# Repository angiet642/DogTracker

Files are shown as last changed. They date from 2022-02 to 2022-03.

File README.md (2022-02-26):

# DogTracker
__Authors: Kylee and Angie__

### Purpose 

A common issue pet-owners face is discovering that their pet has escaped the house. To prevent this situation, our team is interested in designing a low-power dog tracker using LoRa. Unlike other pet-tracking collars, our system will implement a training technique by emitting a 25KHz sound wave if the pet is found outside of a user-defined geo fence. For example, if the user would like to train their dog to avoid a specific area of the backyard, our device will detect whether the dog is in this region and emit the high frequency sound if so.

### System diagram   
The proposed design of the pet-tracker system is illustrated in the block diagram below.
<p>
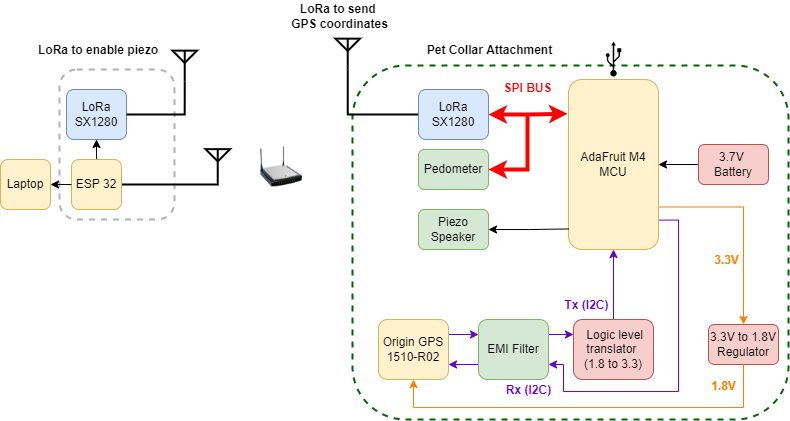
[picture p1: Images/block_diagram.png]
  
  <p> Figure 1: System Level Block Diagram
</p>

### Proposed schedule
| Week  | Date | Tasks 
| --- | --- | --- |
| Week 7 | Feb 13-Feb 19  | - [x] Order parts <br />- [ ] Review PCB and Schematic with Steve and Joanna |
| Week 8 | Feb 20-Feb 26  | - [x] Submit PCB for fabriciation | 
| Week 9 | Feb 27-March 5  | - [ ] Bring up and test boards | 
| Week 10 | March 6-March 12  | - [ ] Demo | 

### Verification
To verify our system, we will first verify the functionality of each module before methodically combining things into our final system. The steps are outlined below.

#### Before final PCB comes back: 
- [x] Upload basic Blink code to M4 Feather Board
- [x] Write basic transmit/recieve code for SX1280 using this [reference](https://github.com/maholli/CircuitPython_SX1280) (In progress)
- [ ] Hook up SX1280 to SPI port of any available micro and run transmit code while probing antenna line with Spectrum Analyzer
- [ ] Connect additional SX1280 board and have both transmit and recieve data \
#### After final PCB comes back:
- [ ] Again, verify transmit and recieve of SX1280 module on our PCB
- [ ] Connect SX1280 to ESP32 (the "base station") and try sending and recieving from our PCB
- [ ] Connect ESP32 to wifi and verify that there isn't any interference between Lora and WIFI
- [ ] Independently turn on GPS and test reading cordinates
- [ ] Turn on both SX1280 and GPS and run code to intermittently send GPS coordinates to "base station" 
- [ ] Configure pedometer to read step count on the microcontroller
- [ ] Read pedometer at the same time as reading GPS and sending Lora
- [ ] Confgure Ultrasonic piezo buzzer and try running at 25kHz, certain apps will verify sound since it's beyond the human range
- [ ] Upload code for runnng piezzo buzzer from the "base station" when dog is out of range
- [ ] Run all four modules at the same time 
- [ ] Have "base station"  upload information to a website hosted on the the Things network

### Demo Plan
Our demo will be putting the collar on a fellow classmate and having them run around the engineering quad to show the real time updates in GPS coordinates on the base station, which will be set up in the lab. Finally, we will show that when our classmate goes out of the user-defined range, the piezzo buzzer will turn on which can be verified with [this app](https://play.google.com/store/apps/details?id=com.microcadsystems.serge.ultrasounddetector&hl=en_US&gl=US)

### In our write up, we will discuss the following
- importance and novelty of the idea 
- description of chosen features 
- high level system discussion
- schematic walkthrough 
- examination of different protocols SPI/I2C/UART 
- Review of RF components eg LoRa, WiFi 
- analysis of challenges or drawbacks
- improvements going forward 
- concluding remarks on our project 

### Challenges
The most difficult steps is getting the PCB right the first time around. We have been meticulously researching parts and going through datasheets to make sure we understand everything that we need for our final PCB. We also plan to have Joanna, Greig, and Steve verify the schematic before we submit it to JLCPCB. 

We have already gotten our parts list checked off and ordered. After submitting our final PCB, we will begin working on the software side of our project. There is a sufficient amount of code to write but none will be outside of our domain given that there's a lot of GPS/LORA/SPI/I2C libraries in Circuit python. 

### Project Links:
Bill of Materials can be found [here](https://github.com/krsandwich/DogTracker/tree/master/Hardware/BOM) \
KICAD Project can be found [here](https://github.com/krsandwich/DogTracker/tree/master/Hardware/Kicad)\
M4 Feather Express Schematic can be found [here](https://learn.adafruit.com/assets/57242)

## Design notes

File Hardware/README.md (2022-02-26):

### 3D PCB

<p>
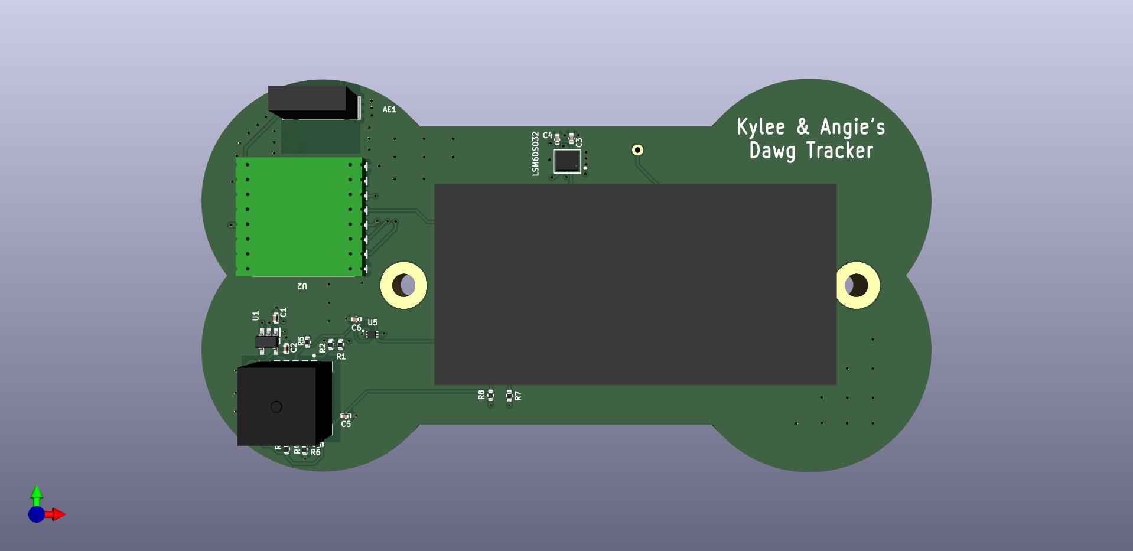
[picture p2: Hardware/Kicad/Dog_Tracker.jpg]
  
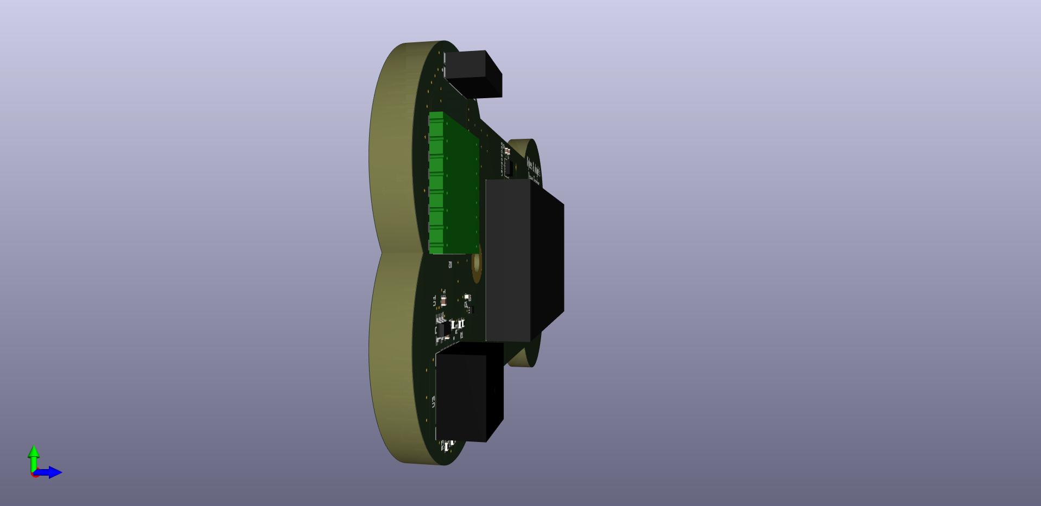
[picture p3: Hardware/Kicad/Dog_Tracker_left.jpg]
  
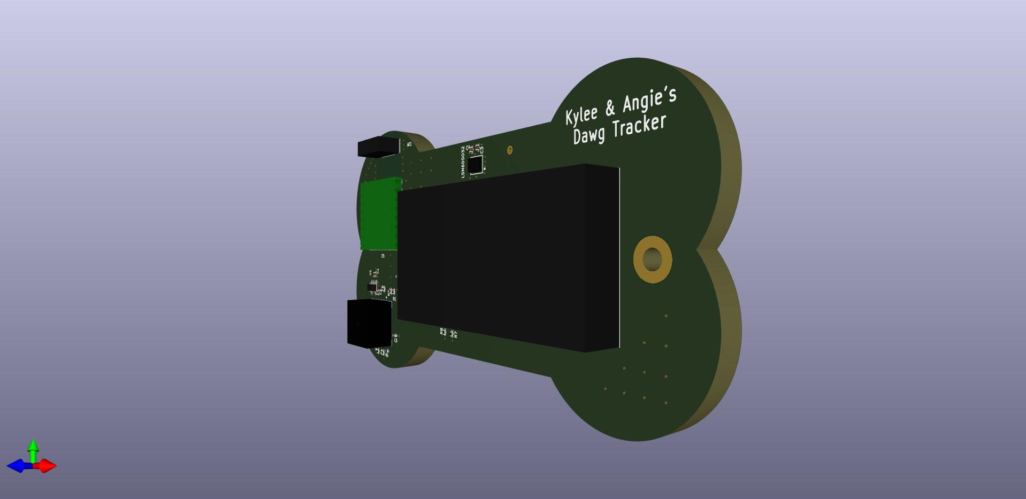
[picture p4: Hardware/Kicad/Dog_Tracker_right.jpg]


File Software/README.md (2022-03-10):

### Useful Links

### ESP32-Wroom
- [ESP pinout](https://docs.espressif.com/projects/esp-idf/en/latest/esp32/_images/esp32-devkitC-v4-pinout.png) 
- [ESP DataSheet](https://www.espressif.com/sites/default/files/documentation/esp32-wroom-32d_esp32-wroom-32u_datasheet_en.pdf)
- [ESP Tutorial](https://randomnerdtutorials.com/installing-the-esp32-board-in-arduino-ide-windows-instructions/)
- [Failed to connect to ESP32: Timed out waiting for packet header](https://randomnerdtutorials.com/solved-failed-to-connect-to-esp32-timed-out-waiting-for-packet-header/) \
- [ESP WebServer Tutorial](https://www.teachmemicro.com/esp32-gps-google-maps/)

### M4 Feather
- [Arduino Tutorial](https://learn.adafruit.com/adafruit-feather-m4-express-atsamd51/using-with-arduino-ide) 
- [Feather pinout](https://cdn-learn.adafruit.com/assets/assets/000/101/972/original/arduino_compatibles_Feather_M4_Page.png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)
### Radio Feather
- [Errors](https://jgromes.github.io/RadioLib/group__status__codes.html#ga5d11e8ce64fb412c2169d0f30b9e9c62) 
- [Schematic](https://cdn-learn.adafruit.com/assets/assets/000/035/125/original/feather_schem.png?1472070266)

### Adafruit ultimate GPS
- [GPS Arduino Tutorial](https://learn.adafruit.com/adafruit-ultimate-gps/parsed-data-output) 
- [GPS Data Conversion Calculator](https://www.pgc.umn.edu/apps/convert/)

### SX1280
- [Tx/Rx Examples, circuit python](https://github.com/maholli/CircuitPython_SX1280)

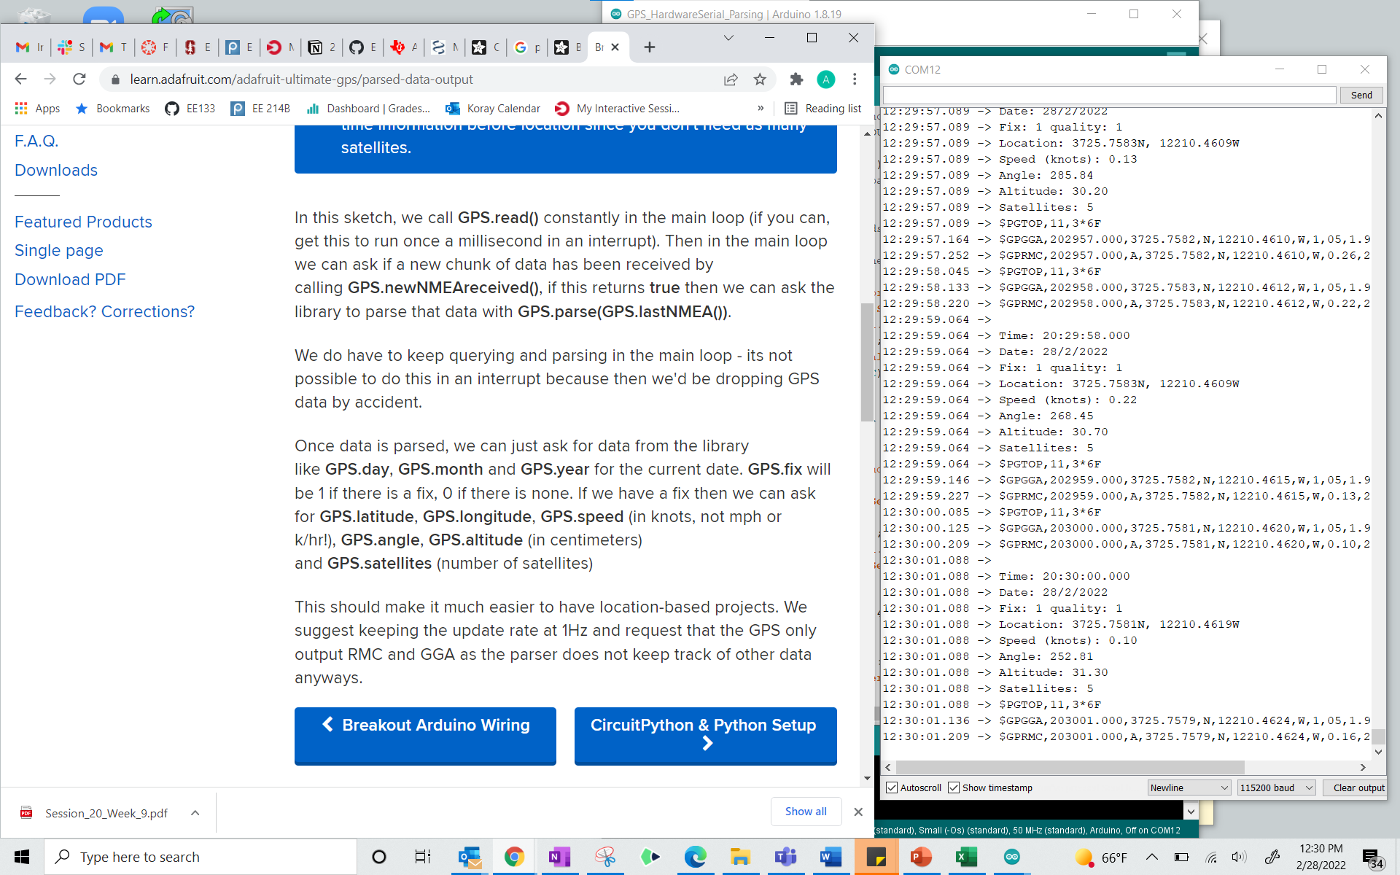
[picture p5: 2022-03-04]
Software/Screenshot 2022-02-28 123524.png

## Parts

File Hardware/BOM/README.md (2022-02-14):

# BOM
| Part number | Description | Price  | Link | Quantity (per board) | Qty Requested | QTY REQUESTED BY STEVE | Total  | Assigned | Datasheet | PCB Layout Tips |
| --- | --- | --- | --- | --- | --- | --- | --- | --- | --- | --- |
| ORG1510-PM01 | Origin GPS | $23 | [link](https://www.embeddedworks.net/satl206/) | 1 | 3 | 4 | $92 | Angie | [datasheet](https://origingps.com/wp-content/uploads/2021/01/Multi-Micro-Hornet-ORG1510-R02-Datasheet-Rev-2.0.pdf) | |
| NFA18SL407V1A45L | EMIFIL Chip (noise attenuator) | $0.55  | [link](https://www.mouser.com/ProductDetail/Murata-Electronics/NFA18SD187X1A45L?qs=MY6wChARw2zlNqdGdvnNNA%3D%3D) | 1 | 2 | 4 | $2.20  | Angie | [datasheet](https://www.mouser.com/datasheet/2/281/Murata%20NF%20Series-1186034.pdf) | Pg 32 |
| SN74AUP1T97DSFR | Voltage Level Translator | $0.65  | [link](https://www.mouser.com/ProductDetail/Texas-Instruments/SN74AUP1T97DSFR?qs=BmtUOLWBNQpU0I2Kw8UnSg%3D%3D) | 1 | 2 | 4 | $2.60  | Angie | [datasheet](https://www.ti.com/lit/ds/symlink/sn74aup1t97.pdf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) | |
| ADP160AUJZ-1.8-R7 | Linear Voltage Regulator (1.8 out) | $1.43  | [link](https://www.mouser.com/ProductDetail/Analog-Devices/ADP160AUJZ-18-R7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) | 1 | 2 | 4 | $5.72  | Angie | [datasheet](https://www.analog.com/media/en/technical-documentation/data-sheets/ADP160_161_162_163.pdf) | |
| W-03A | Ultrasonic Buzzer | $2.96  | [link](https://www.digikey.com/en/products/detail/east-electronics/W-03A/13170527) | 1 | 2 | 2 | $5.92  | Kylee | | |
| SX1280 | LoRA Module | | N/A | 2 | 2 | n/a | 0 | Kylee | | |
| W3211 | Pulse Larsen Antenna 902-928MHz | $2.01  | [link](https://www.digikey.com/en/products/detail/pulselarsen-antennas/W3211/9838684) | 1 | 2 | 2 | $4.02  | | | |
| Adafruit Feather M4 Express | Adafruit Feather M4 Express | $22.95 | [link](https://www.adafruit.com/product/3857) | 1 | 2 | Already have | 0 | Kylee | [datasheet](https://cdn-learn.adafruit.com/downloads/pdf/introducing-adafruit-itsybitsy-m4.pdf) | |
| ASR00003 | Battery with protection Circuit | $3.95  | [link](https://www.digikey.com/en/products/detail/tinycircuits/ASR00003/7404516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) | 1 | 2 | Do we have some? | 0 | Angie | [datasheet](https://media.digikey.com/pdf/Data%20Sheets/TinyCircuits%20PDFs/ASR00003_Web.pdf) | |
| LSM6DSRTR | Accelerometer | $4.97  | [link](https://lcsc.com/product-detail/Motion-Sensors-Accelerometers_STMicroelectronics-LSM6DSRTR_C784817.html) | 1 | 2 | 4 | $19.88 | Kylee | | |
| ESP32-DEVKITC-32U | ESP32 | $10.00 | [link](https://www.digikey.com/en/products/detail/espressif-systems/ESP32-DEVKITC-32U/9357002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) | 1 | 2 | 2 | $20.00 | Kylee | | |
| 2119960100 | wifi antenna | | [link](https://www.digikey.com/en/products/detail/molex/2119960100/10270663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) | 1 | | | | | |

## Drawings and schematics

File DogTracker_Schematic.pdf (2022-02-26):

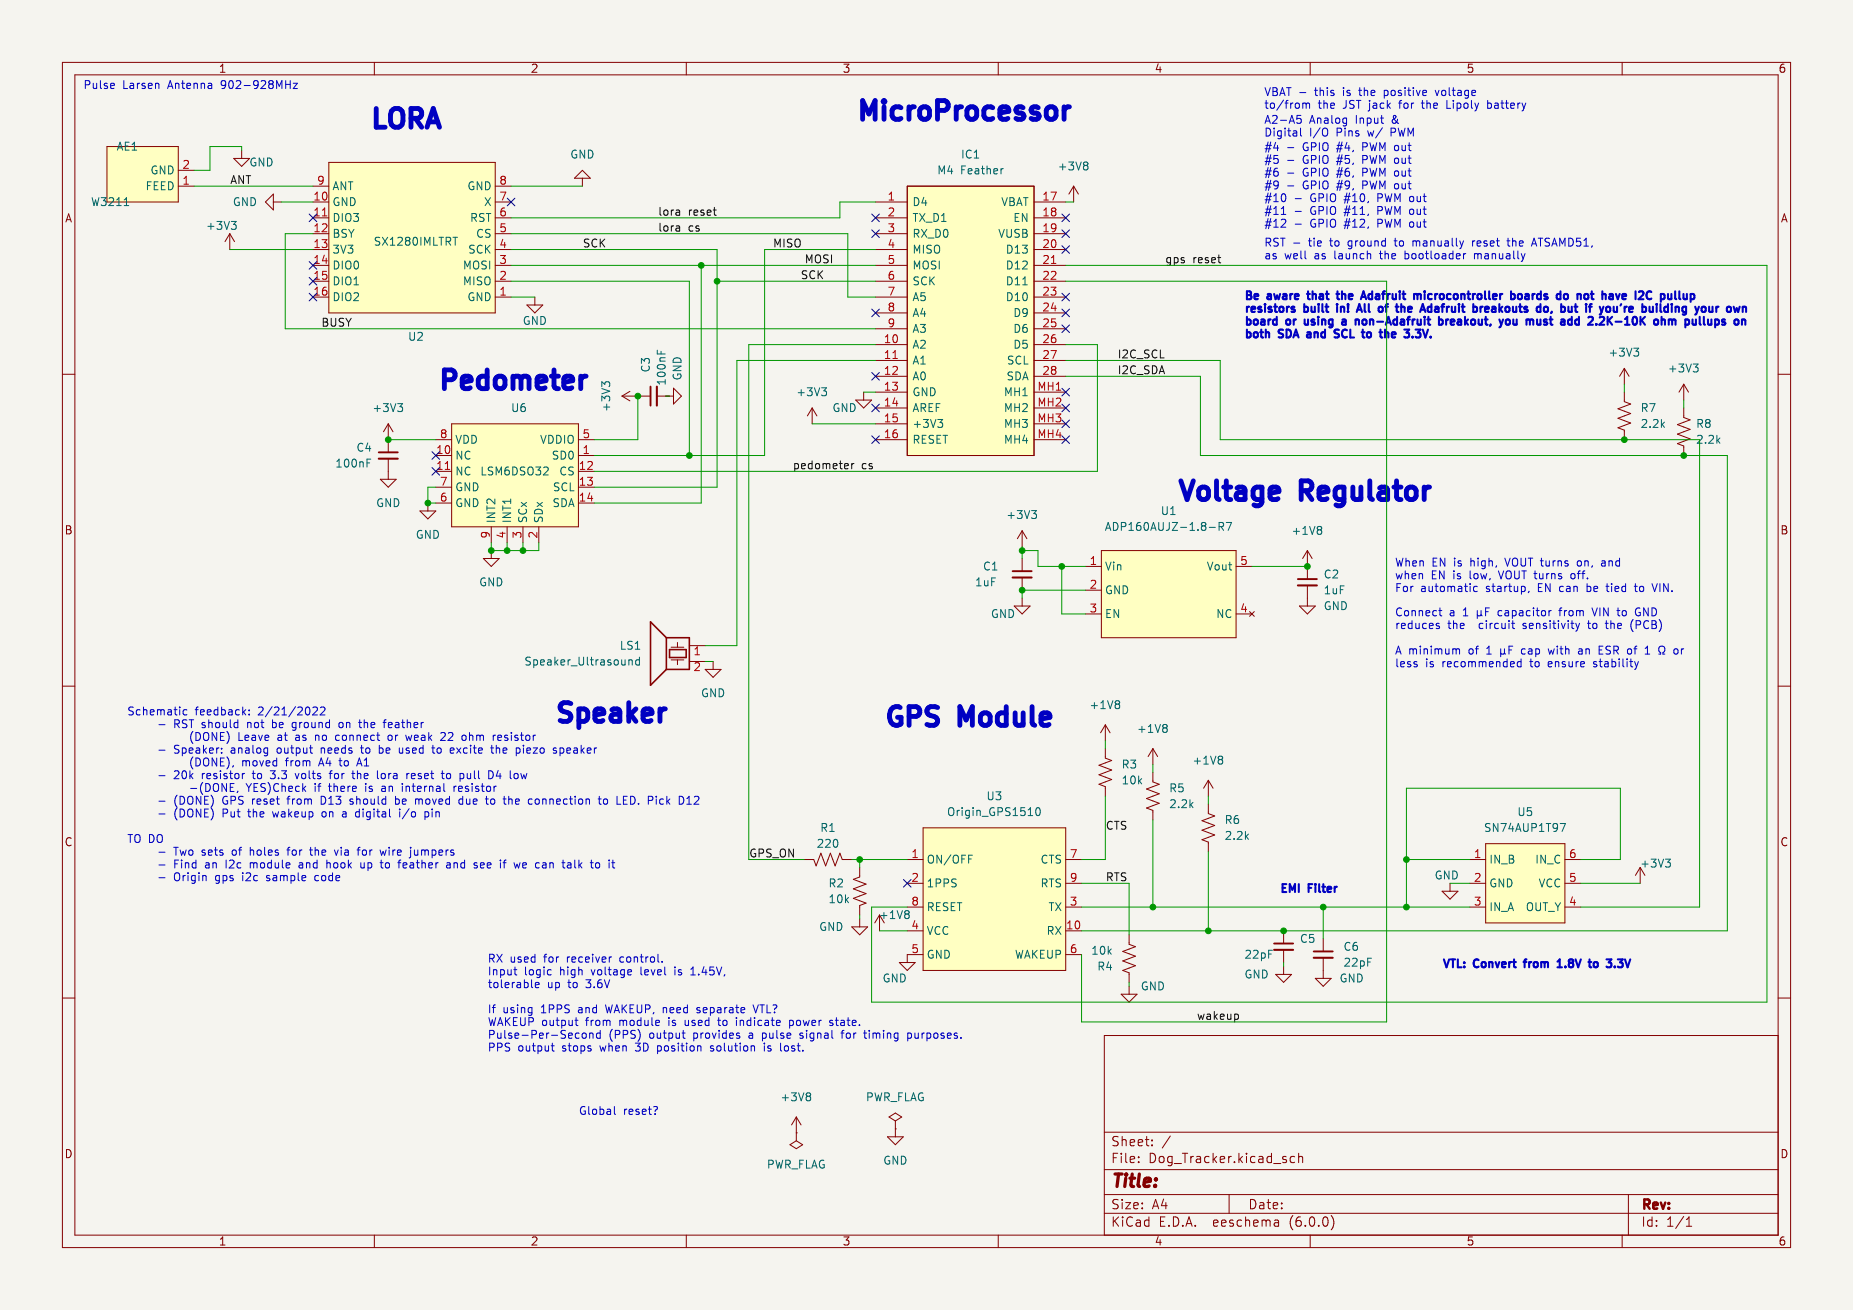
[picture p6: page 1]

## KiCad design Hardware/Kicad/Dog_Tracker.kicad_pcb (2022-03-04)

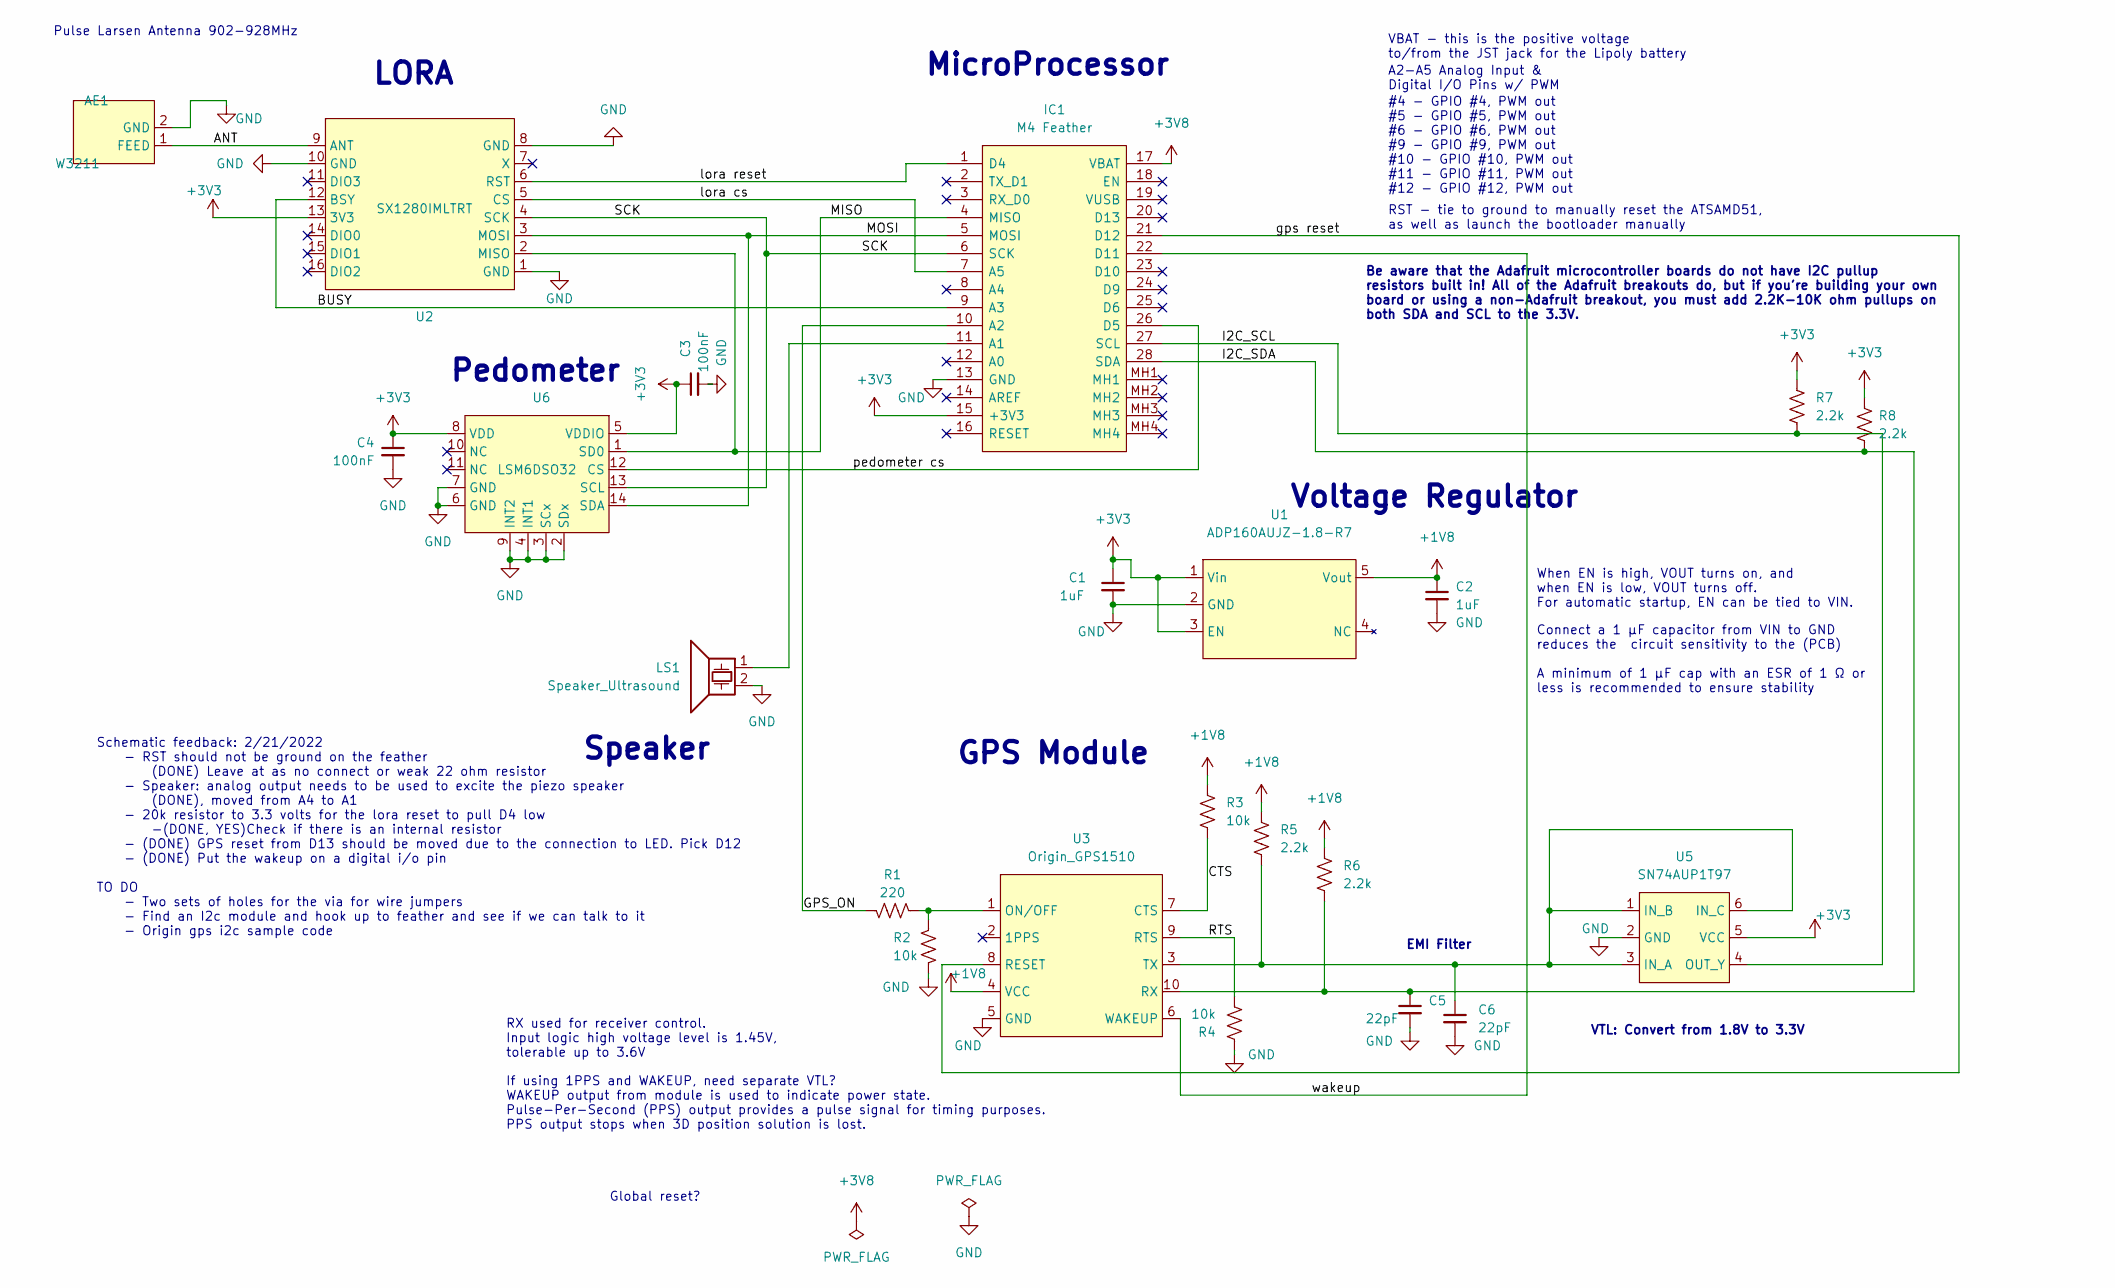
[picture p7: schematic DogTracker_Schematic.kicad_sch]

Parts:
AE1: W3211
C1, C2: 1uF; C_0402_1005Metric
C3, C4: 100nF; C_0402_1005Metric
C5, C6: 22pF; C_0402_1005Metric
IC1: M4 Feather; Feather_M4; Manufacturer_Part_Number 3857; Mouser Part Number 485-3857
LS1: Speaker_Ultrasound; W-03A
R1: 220; R_0402_1005Metric
R2, R3, R4: 10k; R_0402_1005Metric
R5, R6, R7, R8: 2.2k; R_0402_1005Metric
U1: ADP160AUJZ-1.8-R7; SOT95P280X100
U2: SX1280IMLTRT; SX1280_Breakout
U3: Origin_GPS1510; ORG1510
U5: SN74AUP1T97; SN74AUP1T97DSFR
U6: LSM6DSO32; LSM6DSRTR

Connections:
+1V8: C2.1, R3.2, R5.2, R6.2, U1.5 (Vout), U3.4 (VCC)
+3V3: C1.1, C3.1, C4.1, IC1.15 (+3V3), R7.2, R8.2, U1.1 (Vin), U1.3 (EN), U2.13 (3V3), U5.5 (VCC), U6.5 (VDDIO), U6.8 (VDD)
+3V8: IC1.17 (VBAT)
/ANT: AE1.1 (FEED), U2.9 (ANT)
/BUSY: IC1.9 (A3), U2.12 (BSY)
/CTS: R3.1, U3.7 (CTS)
/GPS_ON: IC1.10 (A2), R1.1
/I2C_SCL: IC1.27 (SCL), R7.1, U5.4 (OUT_Y)
/I2C_SDA: C5.1, IC1.28 (SDA), R6.1, R8.1, U3.10 (RX)
/MISO: IC1.4 (MISO), U2.2 (MISO), U6.1 (SD0)
/MOSI: IC1.5 (MOSI), U2.3 (MOSI), U6.14 (SDA)
/RTS: R4.1, U3.9 (RTS)
/SCK: IC1.6 (SCK), U2.4 (SCK), U6.13 (SCL)
/gps reset: IC1.21 (D12), U3.8 (RESET)
/lora cs: IC1.7 (A5), U2.5 (CS)
/lora reset: IC1.1 (D4), U2.6 (RST)
/pedometer cs: IC1.26 (D5), U6.12 (CS)
/wakeup: IC1.22 (D11), U3.6 (WAKEUP)
GND: AE1.2 (GND), C1.2, C2.2, C3.2, C4.2, C5.2, C6.2, IC1.13 (GND), LS1.2, R2.2, R4.2, U1.2 (GND), U2.1 (GND), U2.8 (GND), U2.10 (GND), U3.5 (GND), U5.2 (GND), U6.2 (SDx), U6.3 (SCx), U6.4 (INT1), U6.6 (GND), U6.7 (GND), U6.9 (INT2)
unnamed: C6.1, R5.1, U3.3 (TX), U5.1 (IN_B), U5.3 (IN_A), U5.6 (IN_C)
unnamed: IC1.11 (A1), LS1.1
unnamed: R1.2, R2.1, U3.1 (ON/OFF)

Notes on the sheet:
#4 - GPIO #4, PWM out #5 - GPIO #5, PWM out #6 - GPIO #6, PWM out #9 - GPIO #9, PWM out #10 - GPIO #10, PWM out #11 - GPIO #11, PWM out #12 - GPIO #12, PWM out
VTL: Convert from 1.8V to 3.3V
Pulse Larsen Antenna 902-928MHz
Voltage Regulator
EMI Filter
LORA
Pedometer
VBAT - this is the positive voltage to/from the JST jack for the Lipoly battery
MicroProcessor
RX used for receiver control. Input logic high voltage level is 1.45V, tolerable up to 3.6V
If using 1PPS and WAKEUP, need separate VTL? WAKEUP output from module is used to indicate power state. Pulse-Per-Second (PPS) output provides a pulse signal for timing purposes. PPS output stops when 3D position solution is lost.
When EN is high, VOUT turns on, and when EN is low, VOUT turns off. For automatic startup, EN can be tied to VIN.
A2-A5 Analog Input & Digital I/O Pins w/ PWM
Global reset?
Connect a 1 μF capacitor from VIN to GND reduces the circuit sensitivity to the (PCB) A minimum of 1 μF cap with an ESR of 1 Ω or less is recommended to ensure stability
GPS Module
Schematic feedback: 2/21/2022 - RST should not be ground on the feather (DONE) Leave at as no connect or weak 22 ohm resistor - Speaker: analog output needs to be used to excite the piezo speaker (DONE), moved from A4 to A1 - 20k resistor to 3.3 volts for the lora reset to pull D4 low -(DONE, YES)C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
Be aware that the Adafruit microcontroller boards do not have I2C pullup resistors built in! All of the Adafruit breakouts do, but if you're building your own board or using a non-Adafruit breakout, you must add 2.2K-10K ohm pullups on both SDA and SCL to the 3.3V.
RST - tie to ground to manually reset the ATSAMD51, as well as launch the bootloader manually
Speaker

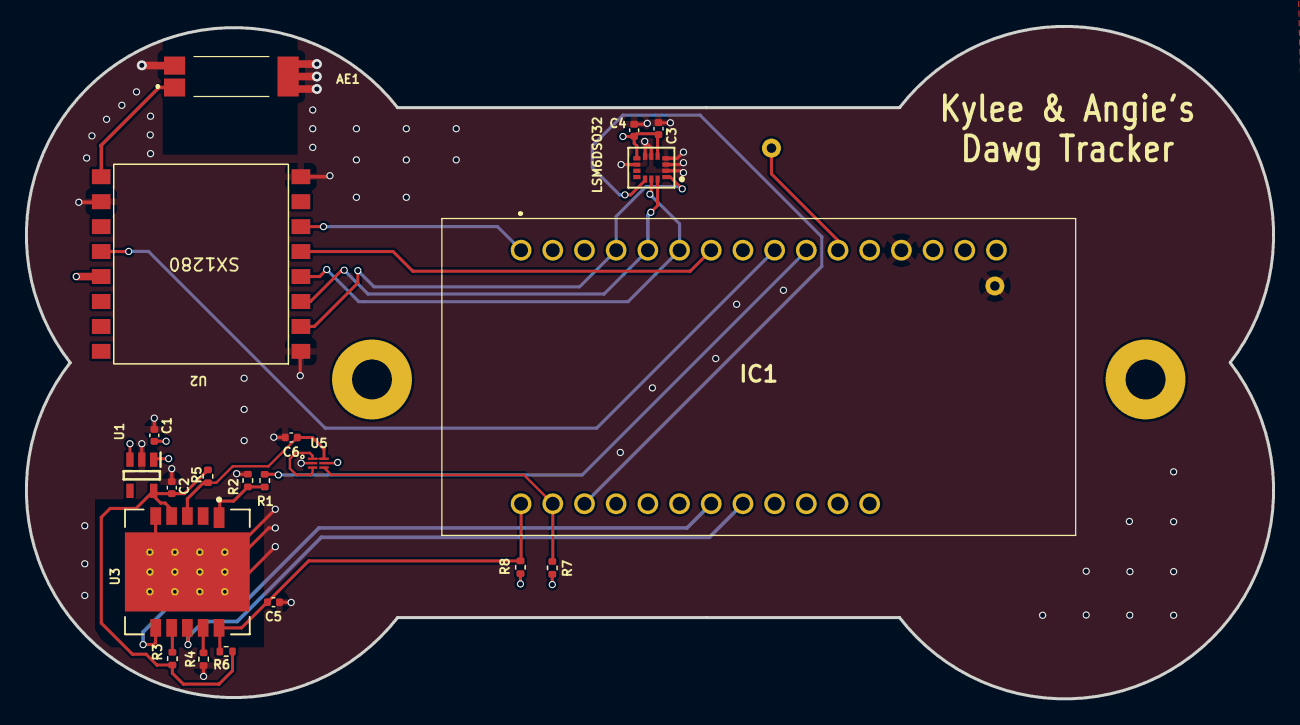
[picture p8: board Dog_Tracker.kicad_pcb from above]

Board: 4 copper layers, 100.0 x 53.9 mm, 22 parts (1 on the bottom side), 21 nets.

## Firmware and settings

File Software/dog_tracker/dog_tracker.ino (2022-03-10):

#include <SPI.h>
#include <RH_RF95.h>
#include <Adafruit_GPS.h>
#define GPSSerial Serial1
#define ALARM_PIN A0
// Connect to the GPS on the hardware port
Adafruit_GPS GPS(&GPSSerial);
uint32_t timer = millis();
uint32_t timer2 = millis();
#define GPSECHO false
/* for ESP w/featherwing */
//#define RFM95_CS  14    // "E"
//#define RFM95_RST 32   // "D"
//#define RFM95_INT 33   // "B"
// feather m4
#define RFM95_CS   5//9 //32    // "E"
#define RFM95_RST  6//10 //15   // "D"
#define RFM95_INT  10//19 //14   // "B"
#define RF95_FREQ 915.0
#define LED 13 // Blinky on receipt

#include <Wire.h>
#include <Adafruit_MMA8451.h>
#include <Adafruit_Sensor.h>
int accum = 0;
String kylee_data = "3746.4940N, 12225.1640W, 6/6/6666 66:66:66.000";
RH_RF95 rf95(RFM95_CS, RFM95_INT);
Adafruit_MMA8451 mma = Adafruit_MMA8451();

void setup() {
  // -------------------------------------- TX SET UP -----------------------------------------------
  pinMode(LED, OUTPUT);
  pinMode(RFM95_RST, OUTPUT);
  digitalWrite(RFM95_RST, HIGH);
  Serial.begin(115200);
  while (!Serial) {
    delay(1);
  }
  delay(100);
  Serial.println("Feather LoRa TX Test!");
  // manual reset
  digitalWrite(RFM95_RST, LOW);
  delay(10);
  digitalWrite(RFM95_RST, HIGH);
  delay(10);
  while (!rf95.init()) {
    Serial.println("LoRa radio init failed");
    while (1);
  }
  Serial.println("LoRa radio init OK!");
  // Defaults after init are 434.0MHz, modulation GFSK_Rb250Fd250, +13dbM
  if (!rf95.setFrequency(RF95_FREQ)) {
    Serial.println("setFrequency failed");
    while (1);
  }
  Serial.print("Set Freq to: "); Serial.println(RF95_FREQ);
  rf95.setTxPower(23, false);
  Serial.println("Adafruit GPS library basic parsing test!");

  // -------------------------------------- GPS SET UP -----------------------------------------------
  GPS.begin(9600);
  GPS.sendCommand(PMTK_SET_NMEA_OUTPUT_RMCGGA);
  GPS.sendCommand(PMTK_SET_NMEA_UPDATE_1HZ); // 1 Hz update rate
  GPS.sendCommand(PGCMD_ANTENNA);
  delay(1000);
  // Ask for firmware version
  GPSSerial.println(PMTK_Q_RELEASE);

  // -------------------------------------- Accelerometer SET UP -------------------------------------
  Serial.println("Adafruit MMA8451 test!");
  if (! mma.begin()) {
    Serial.println("Couldnt start");
    while (1);
  }
  Serial.println("MMA8451 found!");
  mma.setRange(MMA8451_RANGE_2_G);
  Serial.print("Range = "); Serial.print(2 << mma.getRange());
  Serial.println("G");
}

void loop() {
  Serial.println("------------Reading GPS...------------"); 
  readGPSData();
  Serial.println("------------Step Count...------------");   
  pedometerCount();
//  if (millis() - timer2 < 5000) {
//    return;
//  }
//   timer2 = millis();
 delay(1000); // Wait 1 second between transmits, could also 'sleep' here!
  Serial.println("------------Transmitting...------------"); // Send a message to rf95_server
  char tx_buf[60];
  memset(tx_buf, 0, sizeof(tx_buf));
  kylee_data.toCharArray(tx_buf, 60);
  Serial.println(tx_buf);
  Serial.println("Sending...");
  delay(10);
  rf95.send((uint8_t *)tx_buf, 60);
  Serial.println("Waiting for packet to complete...");
  delay(10);
  rf95.waitPacketSent();
  // Now wait for a reply
  uint8_t rx_buf[RH_RF95_MAX_MESSAGE_LEN];
  uint8_t len = sizeof(rx_buf);
  Serial.println("Waiting for reply...");
  if (rf95.waitAvailableTimeout(1000)) {
    // Should be a reply message for us now
    if (rf95.recv(rx_buf, &len)) {
      Serial.print("Got reply: ");
      Serial.println((char*)rx_buf);
      Serial.print("RSSI: ");
      Serial.println(rf95.lastRssi(), DEC);
      if (rx_buf[0] == 'N') {
        playAlarm();
      }
    }
    else {
      Serial.println("Receive failed");
    }
  }
  else {
    Serial.println("No reply, is there a listener around?");
  }
}
void readGPSData() {
//  // read data from the GPS in the 'main loop'
  char c;
  for (int i = 0; i <= 100; i++) {
//    if(GPS.available()){
      c = GPS.read();
//    }
  }  
//  char c = GPS.read();
  if (GPSECHO)
    if (c) Serial.print(c);
  if (GPS.newNMEAreceived()) {
    Serial.print(GPS.lastNMEA()); // this also sets the newNMEAreceived() flag to false
    if (!GPS.parse(GPS.lastNMEA())) // this also sets the newNMEAreceived() flag to false
      return; // we can fail to parse a sentence in which case we should just wait for another
  }
  if (millis() - timer > 2000) {
    timer = millis(); // reset the timer
    Serial.print("\nTime: ");
    if (GPS.hour < 10) {
      Serial.print('0');
    }
    Serial.print(GPS.hour, DEC); Serial.print(':');
    if (GPS.minute < 10) {
      Serial.print('0');
    }
    Serial.print(GPS.minute, DEC); Serial.print(':');
    if (GPS.seconds < 10) {
      Serial.print('0');
    }
    Serial.print(GPS.seconds, DEC); Serial.print('.');
    if (GPS.milliseconds < 10) {
      Serial.print("00");
    } else if (GPS.milliseconds > 9 && GPS.milliseconds < 100) {
      Serial.print("0");
    }
    Serial.println(GPS.milliseconds);
    Serial.print("Date: ");
    Serial.print(GPS.day, DEC); Serial.print('/');
    Serial.print(GPS.month, DEC); Serial.print("/20");
    Serial.println(GPS.year, DEC);
    Serial.print("Fix: "); Serial.print((int)GPS.fix);
    Serial.print(" quality: "); Serial.println((int)GPS.fixquality);
    if (GPS.fix) {
      Serial.println("Example code");
      Serial.print("Location: ");
      Serial.print(GPS.latitude, 4); Serial.print(GPS.lat);
      Serial.print(", ");
      Serial.print(GPS.longitude, 4); Serial.println(GPS.lon);
      float gps_latitude = GPS.latitude;
      char gps_lat_dir = GPS.lat;
      float gps_longitude = GPS.longitude;
      char gps_lon_dir = GPS.lon;
      kylee_data = String(gps_latitude, 6) + gps_lat_dir + ", " + String(gps_longitude, 6) + gps_lon_dir + ",  " + String(GPS.day) + "/" + String(GPS.month) + "/" + String(GPS.year) + " " + String(GPS.hour) + ":" + String(GPS.minute) + ":" + String(GPS.seconds) + ", " + String(accum);
      digitalWrite(LED, HIGH);    
      delay(1000);
      digitalWrite(LED, LOW); 
    }
    Serial.println(kylee_data);
  }
}

void playAlarm() {
  tone(ALARM_PIN, 20000, 3000); // play for 3 seconds
}

void pedometerCount() {
  // Read the 'raw' data in 14-bit counts
  mma.read();
//  Serial.print("X:\t"); Serial.println(mma.x);
//  Serial.print("Y:\t"); Serial.println(mma.y);
//  Serial.print("Z:\t"); Serial.println(mma.z);
//  Serial.println();

  /* Get a new sensor event */
  sensors_event_t event;
  mma.getEvent(&event);

  /* Display the results (acceleration is measured in m/s^2) */
  Serial.print("X: "); Serial.println(event.acceleration.x);
  Serial.print("Y: "); Serial.println(event.acceleration.y);
  Serial.print("Z: "); Serial.println(event.acceleration.z);
  Serial.println("m/s^2 ");

  if (event.acceleration.x >= abs(1)) {
    Serial.println("Update Step");
    accum = accum + 1;
  }
  Serial.print("Step Counter: "); Serial.println(accum);
  uint8_t o = mma.getOrientation();
  Serial.println();
  delay(500);
}

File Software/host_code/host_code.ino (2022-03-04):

// for forwarding run ./ngrok tcp 172.20.10.5:8888 --authtoken <token>
// Load Wi-Fi library
#include <WiFi.h>

// Replace with your network credentials
const char* ssid = "SSID";
const char* password = "PASSWORD";

// Set web server port number to 80
WiFiServer server(80);

// Variable to store the HTTP request
String header;


void setup() {
  Serial.begin(115200);
  
  Serial.print("Connecting to ");
  Serial.println(ssid);
  WiFi.begin(ssid, password);
  while (WiFi.status() != WL_CONNECTED) {
    delay(500);
    Serial.print(".");
  }
  // Print local IP address and start web server
  Serial.println("");
  Serial.println("WiFi connected.");
  Serial.println("IP address: ");
  Serial.println(WiFi.localIP());
  server.begin();
}

void loop(){
  WiFiClient client = server.available();   // Listen for incoming clients
  
    if (client) {                             // If a new client connects,
    Serial.println("New Client.");          // print a message out in the serial port
    String currentLine = "";                // make a String to hold incoming data from the client
    while (client.connected()) 
    {            // loop while the client's connected
      if (client.available()) {             // if there's bytes to read from the client,
        char c = client.read();             // read a byte, then
        Serial.write(c);                    // print it out the serial monitor
        header += c;
        if (c == '\n') {                    // if the byte is a newline character
          // if the current line is blank, you got two newline characters in a row.
          // that's the end of the client HTTP request, so send a response:
          if (currentLine.length() == 0) {
            
            client.println("HTTP/1.1 200 OK");
            client.println("Content-type:text/html");
            client.println("Connection: close");
            client.println();
            client.println("<!DOCTYPE html>\n");
            client.println("<html>\n");
            client.println("<body>\n");
            client.println("<center>\n");
            client.println("<h1>Kylee & Angie's Dawg Tracker </h1>\n");
            client.println("<div id=\"googleMap\" style=\"width:100%;height:400px;\"></div>\n");
            client.println("<script>\n");
            client.println("function myMap() {\n");
            client.println("var mapProp= {\n");
            client.println("center:new google.maps.LatLng(51.508742,-0.120850),\n");
            client.println("zoom:5,\n");
            client.println("};\n");
            client.println("var map = new google.maps.Map(document.getElementById(\"googleMap\"),mapProp);\n");
            client.println("}\n");
            client.println("</script>\n");
            client.println("<script src=\"https://maps.googleapis.com/maps/api/js?key=<PUT KEY HERE>&callback=myMap\"></script>\n");
            client.println("</center>\n");
            client.println("</body>\n");
            client.println("</html>");
            break;
           
          } 
          else { // if you got a newline, then clear currentLine
            currentLine = "";
          }
        } else if (c != '\r') {  // if you got anything else but a carriage return character,
          currentLine += c;      // add it to the end of the currentLine
        }
      }
    }
    // Clear the header variable
    header = "";
    // Close the connection
    client.stop();
    Serial.println("Client disconnected.");
    Serial.println("");
  }
}

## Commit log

2022-02-11 update symbols
    [DogTracker.kicad_sch]
2022-02-12 'updated feather'
    [DogTracker.kicad_sch]
2022-02-13 add text, hope this works
    [DogTracker.kicad_sch]
2022-02-13 'rearrange schematic'
    [DogTracker.kicad_sch]
2022-02-14 BOM info
    [DogTracker.kicad_pcb, DogTracker.kicad_sch]
2022-02-14 update bom
2022-02-14 change folder name
    [DogTracker.kicad_pcb, DogTracker.kicad_sch]
2022-02-14 folder name changed
    [DogTracker.kicad_pcb, DogTracker.kicad_sch]
2022-02-14 update schematic
    [DogTracker.kicad_sch]
2022-02-14 update reset
    [DogTracker.kicad_sch]
2022-02-14 fixed pedometer
    [Dog_Tracker.kicad_pcb, Dog_Tracker.kicad_sch]
2022-02-14 'assigned footprints'
    [Dog_Tracker.kicad_sch]
2022-02-14 update last footprint
    [Dog_Tracker.kicad_sch]
2022-02-15 'wire the schematic'
    [Dog_Tracker_COPY.kicad_sch]
2022-02-15 'wire i2c'
    [Dog_Tracker.kicad_sch]
2022-02-15 schematic fixed
    [Dog_Tracker.kicad_sch]
2022-02-16 'fixed erc, need to fix warnings'
    [Dog_Tracker.kicad_sch]
2022-02-16 no errors, no warnings
    [Dog_Tracker.kicad_sch]
2022-02-21 footprint speaker
    [Dog_Tracker.kicad_sch]
2022-02-22 removed footprints and added the origin gps only. updated schematic per steves feedback
    [Dog_Tracker.kicad_sch]
2022-02-22 added footprints
    [Dog_Tracker.kicad_sch]
2022-02-22 'update 3214 to 3211'
    [Dog_Tracker.kicad_sch]
2022-02-22 'pcb floor plan initiated'
    [Dog_Tracker.kicad_pcb, Dog_Tracker.kicad_sch]
2022-02-22 fixed all footprint and added SX1280
    [Dog_Tracker.kicad_pcb, Dog_Tracker.kicad_sch]
2022-02-23 'remove emi filter and use caps'
    [Dog_Tracker.kicad_pcb, Dog_Tracker.kicad_sch]
2022-02-24 pcb check
    [Dog_Tracker.kicad_pcb, Dog_Tracker.kicad_sch]
2022-02-24 layout done
    [Dog_Tracker.kicad_pcb]
2022-02-26 'update pcb based on steves comments'
    [Dog_Tracker.kicad_pcb]
2022-02-26 fixed footprint
    [DogTracker_Schematic.kicad_sch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]
2022-02-26 'add vias'
    [Dog_Tracker-B_Cu.gbr, Dog_Tracker-B_Mask.gbr, Dog_Tracker-B_Paste.gbr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]
2022-02-26 'update schematic pdf'
2022-02-28 added esp32 code
2022-03-04 'sent for fab'
    [Dog_Tracker-B_Cu.gbr, Dog_Tracker-B_Mask.gbr, Dog_Tracker-B_Paste.gbr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]
